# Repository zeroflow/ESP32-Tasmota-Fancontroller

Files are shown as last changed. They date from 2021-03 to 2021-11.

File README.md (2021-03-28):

# ESP32 Tasmota-Fancontroller

## THIS MODULE HAS NOT YET BEEN BUILT, WORK IN PROGRESS
 
* 4x PWM Fan Output (3 Pin Fan Control not supported)
* 1x BME280 Header
* 1x Spare Header (3V3, GND, 4x IO)

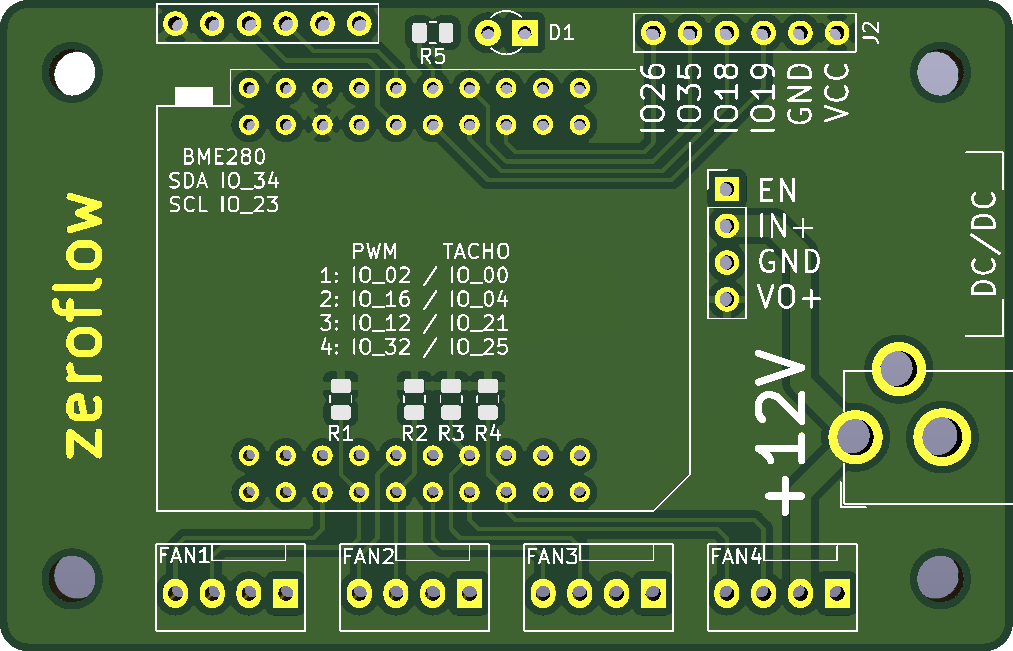
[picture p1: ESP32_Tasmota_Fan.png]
Board Screenshot


## Tasmota Config

* Individual PWM Channel control
* Gamma correction OFF (0..100 = 0%..100% PWM, by default, Tasmota uses a [Gamma Table](https://tasmota.github.io/docs/Lights/#gamma-correction))

`Backlog Setoption68 1; LedTable 0`

## Tasmota32 Template

`{"NAME":"ESP32-Fancontroller","GPIO":[352,0,416,0,353,0,0,0,418,0,0,0,417,0,1,1,0,354,0,608,0,355,1,0,0,0,0,0,419,544,640,1,0,0,0,0],"FLAG":0,"BASE":1}`

| Function | Pin |
| --- | --- |
| Sense1 | IO_00 |
| PWM1 | IO_02 |
| Sense2 | IO_04 |
| PWM3 | IO_12 |
| PWM2 | IO_16 |
| Spare | IO_18 |
| Spare | IO_19 |
| Sense3 | IO_21 |
| BME280 SCL | IO_23 |
| Sense4 | IO_25 |
| Spare | IO_26 |
| PWM4 | IO_32 |
| Link | IO_33 |
| BME280 SDA | IO_34 |
| Spare | IO_35 |

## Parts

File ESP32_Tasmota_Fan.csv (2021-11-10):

Comment | Designator | Footprint | LCSC
1uF/10V | C1 | Capacitor_SMD:C_0805_2012Metric | C1779
330uF/6.3V | C2,C4 | Capacitor_Tantalum_SMD:CP_EIA-3528-15_AVX-H | C16133
1uF | C3,C5 | Capacitor_SMD:C_0805_2012Metric | C1779
LED | D1 | LED_SMD:LED_0805_2012Metric | C2296
1N5820/SS34 | D2 | Diode_SMD:D_SMA | C8678
ZMM5V6 | D3 | Diode_SMD:D_MiniMELF | C8062
Conn_01x04 | FAN1,FAN2,FAN3,FAN4 | Connector:FanPinHeader_1x04_P2.54mm_Vertical
MountingHole | H1,H2,H3,H4 | MountingHole:MountingHole_3.2mm_M3_Pad_Via
XL1509-ADJE1 | IC1 | CSE:SOIC127P600X175-8N | C74192
Conn_01x02_Female | J1 | Connector_BarrelJack:BarrelJack_CUI_PJ-102AH_Horizontal
Conn_01x06 | J2 | Connector_PinHeader_2.54mm:PinHeader_1x06_P2.54mm_Vertical
Conn_01x10 | J3 | Connector_PinSocket_2.54mm:PinSocket_1x10_P2.54mm_Vertical
33uH | L1 | Inductor_SMD:L_TDK_SLF7045 | C13754
AO3401A | Q1 | Package_TO_SOT_SMD:SOT-23 | C15127
4k7 | R1 | Resistor_SMD:R_0805_2012Metric | C17673
100R | R3,R4,R8,R10,R12 | Resistor_SMD:R_0805_2012Metric | C17408
1k | R2 | Resistor_SMD:R_0805_2012Metric | C17513
2k7 | R20 | Resistor_SMD:R_0805_2012Metric | C17530
1k6 | R21 | Resistor_SMD:R_0805_2012Metric | C17394
10k | R5,R6,R7,R9,R11 | Resistor_SMD:R_0805_2012Metric | C17414
ESP32-WROOM-E | U1 | espressif:ESP32-WROOM-32E | C701341

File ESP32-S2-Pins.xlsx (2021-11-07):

Name | No. | Type | Fixed / Comment | Comments | GPIO | RTC GPIO | Special | ADC | DAC | Touch | JTAG | UART | SPI
GND | 1 | P | Ground
3V3 | 2 | P | Power supply | 500mA or more
IO0 | 3 | I/O/T | Bootstrap / Flashing |  | GPIO0 | RTC_GPIO0
IO1 | 4 | I/O/T |  |  | GPIO1 | RTC_GPIO1 |  | ADC1_CH0 |  | TOUCH1
IO2 | 5 | I/O/T |  |  | GPIO2 | RTC_GPIO2 |  | ADC1_CH1 |  | TOUCH2
IO3 | 6 | I/O/T |  |  | GPIO3 | RTC_GPIO3 |  | ADC1_CH2 |  | TOUCH3
IO4 | 7 | I/O/T |  |  | GPIO4 | RTC_GPIO4 |  | ADC1_CH3 |  | TOUCH4
IO5 | 8 | I/O/T |  |  | GPIO5 | RTC_GPIO5 |  | ADC1_CH4 |  | TOUCH5
IO6 | 9 | I/O/T |  |  | GPIO6 | RTC_GPIO6 |  | ADC1_CH5 |  | TOUCH6
IO7 | 10 | I/O/T |  |  | GPIO7 | RTC_GPIO7 |  | ADC1_CH6 |  | TOUCH7
IO8 | 11 | I/O/T |  |  | GPIO8 | RTC_GPIO8 |  | ADC1_CH7 |  | TOUCH8
IO9 | 12 | I/O/T |  |  | GPIO9 | RTC_GPIO9 |  | ADC1_CH8 |  | TOUCH9 |  |  | FSPIHD
IO10 | 13 | I/O/T |  |  | GPIO10 | RTC_GPIO10 |  | ADC1_CH9 |  | TOUCH10 |  |  | FSPICS0, FSPIIO4
IO11 | 14 | I/O/T |  |  | GPIO11 | RTC_GPIO11 |  | ADC2_CH0 |  | TOUCH11 |  |  | FSPID, FSPIIO5
IO12 | 15 | I/O/T |  |  | GPIO12 | RTC_GPIO12 |  | ADC2_CH1 |  | TOUCH12 |  |  | FSPICLK, FSPIIO6
IO13 | 16 | I/O/T |  |  | GPIO13 | RTC_GPIO13 |  | ADC2_CH2 |  | TOUCH13 |  |  | FSPIQ, FSPIIO7
IO14 | 17 | I/O/T |  |  | GPIO14 | RTC_GPIO14 |  | ADC2_CH3 |  | TOUCH14 |  |  | FSPIWP, FSPIDQS
IO15 | 18 | I/O/T |  |  | GPIO15 | RTC_GPIO15 | XTAL_32K_P | ADC2_CH4 |  |  |  | U0RTS
IO16 | 19 | I/O/T |  |  | GPIO16 | RTC_GPIO16 | XTAL_32K_N | ADC2_CH5 |  |  |  | U0CTS
IO17 | 20 | I/O/T |  |  | GPIO17 | RTC_GPIO17 |  | ADC2_CH6 | DAC_1 |  |  | U1TXD
IO18 | 21 | I/O/T |  |  | GPIO18 | RTC_GPIO18 |  | ADC2_CH7 | DAC_2 |  |  | U1RXD | CLK_OUT3
IO19 | 22 | I/O/T | Native USB |  | GPIO19 | RTC_GPIO19 | USB_D- | ADC2_CH8 |  |  |  | U1RTS | CLK_OUT2
IO20 | 23 | I/O/T | Native USB |  | GPIO20 | RTC_GPIO20 | USB_D+ | ADC2_CH9 |  |  |  | U1CTS | CLK_OUT1
IO21 | 24 | I/O/T |  |  | GPIO21 | RTC_GPIO21
IO26 | 25 | I/O/T | DO NOT USE | CS for PSRAM | GPIO26 |  |  |  |  |  |  |  | SPICS1
GND | 26 | P | Ground
IO33 | 27 | I/O/T |  |  | GPIO33 |  |  |  |  |  |  |  | FSPIHD, SPIIO4
IO34 | 28 | I/O/T |  |  | GPIO34 |  |  |  |  |  |  |  | FSPICS0, SPIIO5
IO35 | 29 | I/O/T |  |  | GPIO35 |  |  |  |  |  |  |  | FSPID, SPIIO6
IO36 | 30 | I/O/T |  |  | GPIO36 |  |  |  |  |  |  |  | FSPICLK, SPIIO7
IO37 | 31 | I/O/T |  |  | GPIO37 |  |  |  |  |  |  |  | FSPIQ, SPIDQS
IO38 | 32 | I/O/T |  |  |  |  |  |  |  |  |  |  | FSPIWP
IO39 | 33 | I/O/T |  |  | GPIO39 |  |  |  |  |  | MTCK |  | CLK_OUT3
IO40 | 34 | I/O/T |  |  | GPIO40 |  |  |  |  |  | MTDO |  | CLK_OUT2
IO41 | 35 | I/O/T |  |  | GPIO41 |  |  |  |  |  | MTDI |  | CLK_OUT1
IO42 | 36 | I/O/T |  |  | GPIO42 |  |  |  |  |  | MTMS
TXD0 | 37 | I/O/T | Flashing |  | GPIO43 |  |  |  |  |  |  | U0TXD | CLK_OUT1
RXD0 | 38 | I/O/T | Flashing |  | GPIO44 |  |  |  |  |  |  | U0RXD | CLK_OUT2
IO45 | 39 | I/O/T | Bootstrap |  | GPIO45
IO46 | 40 | I | Bootstrap |  | GPIO46
EN | 41 | I | Pull-Up | R = 10 kΩ and C = 1 µF | High: on, enables the chip. Low: off, the chip powers off. Note: Do not leave the EN pin floating.
GND | 42 | P | Ground
https://docs.espressif.com/projects/esp-idf/en/latest/esp32s2/api-reference/peripherals/gpio.html
Strapping pin: GPIO0, GPIO45 and GPIO46 are strapping pins. For more infomation, please refer to ESP32-S2 datasheet (https://www.espressif.com/sites/default/files/documentation/esp32-s2_datasheet_en.pdf)
SPI0/1: GPIO26-32 are usually used for SPI flash and PSRAM and not recommended for other uses.
JTAG: GPIO39-42 are usually used for inline debug.
GPI: GPIO46 is fixed to pull-down and is input only.

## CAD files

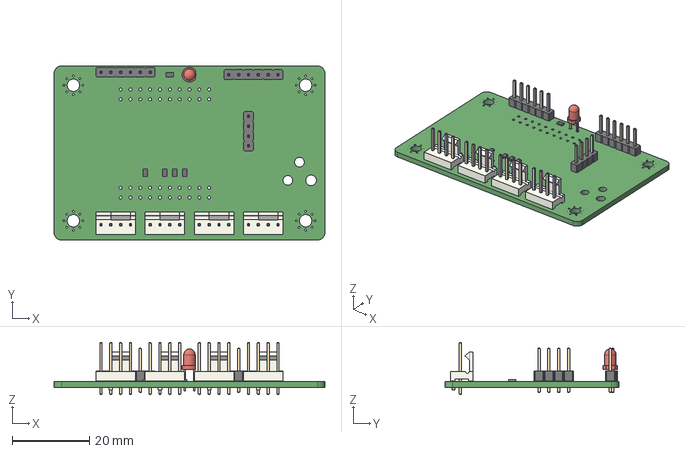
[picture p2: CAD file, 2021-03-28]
ESP32_Tasmota_Fan.step
70.0 x 45.0 x 13.5 mm

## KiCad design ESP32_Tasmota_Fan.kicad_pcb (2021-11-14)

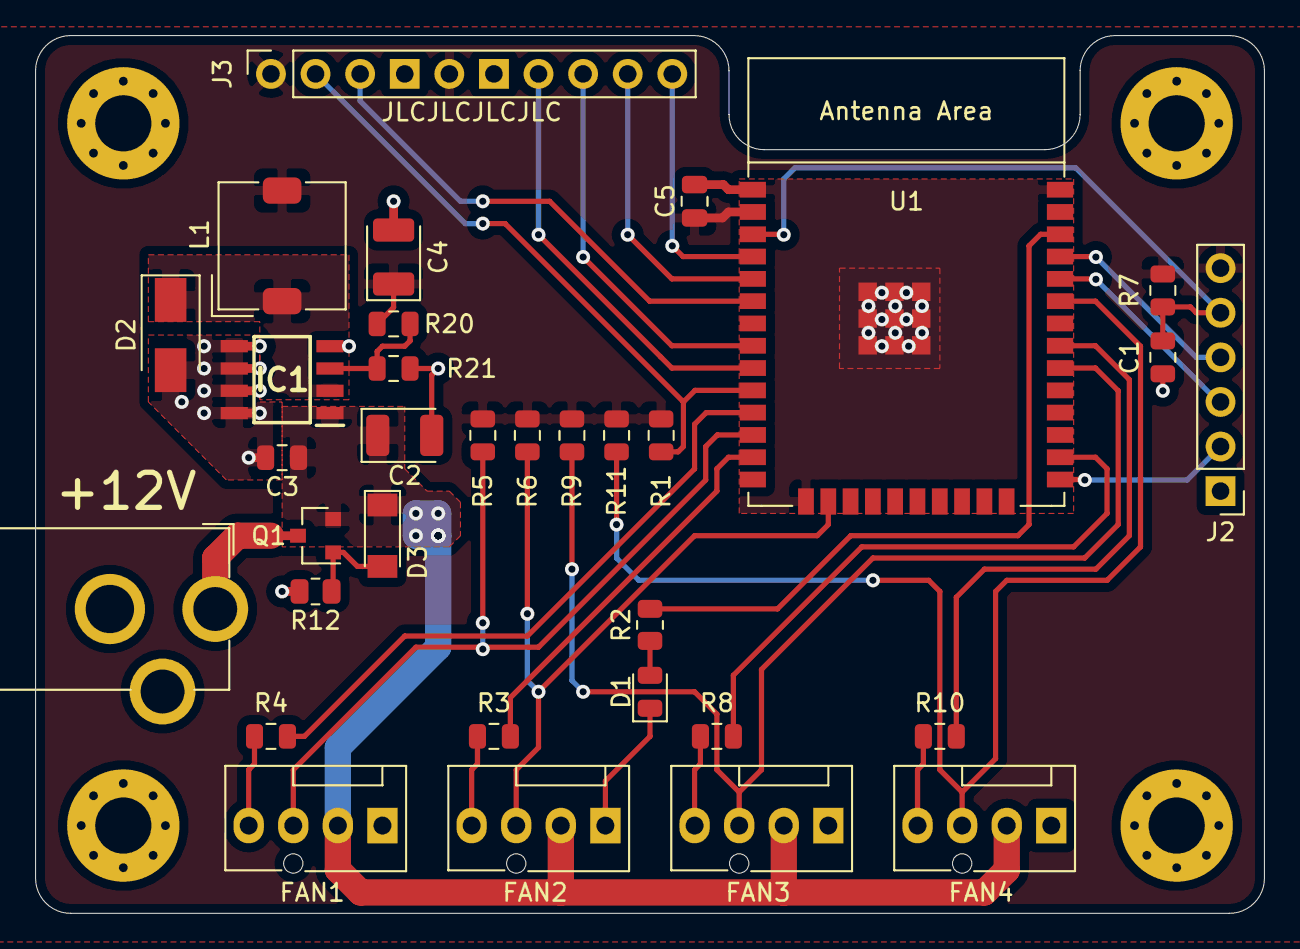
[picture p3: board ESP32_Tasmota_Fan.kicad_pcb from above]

Board: 2 copper layers, 70.0 x 50.0 mm, 37 parts (0 on the bottom side), 31 nets.

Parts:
C1: 1uF/10V; C_0805_2012Metric
C2, C4: 330uF/6.3V; CP_EIA-3528-15_AVX-H
C3, C5: 1uF; C_0805_2012Metric
D1: LED; LED_0805_2012Metric
D2: 1N5820/SS34; D_SMA
D3: ZMM5V6; D_MiniMELF
FAN1, FAN2, FAN3, FAN4: Conn_01x04; FanPinHeader_1x04_P2.54mm_Vertical
H1, H2, H3, H4: MountingHole; MountingHole_3.2mm_M3_Pad_Via
IC1: XL1509-ADJE1; SOIC127P600X175-8N
J1: Conn_01x02_Female; BarrelJack_CUI_PJ-102AH_Horizontal
J2: Conn_01x06; PinHeader_1x06_P2.54mm_Vertical
J3: Conn_01x10; PinSocket_1x10_P2.54mm_Vertical
L1: 33uH; L_TDK_SLF7045
Q1: AO3401A; SOT-23
R1: 4k7; R_0805_2012Metric
R2: 1k; R_0805_2012Metric
R3, R4, R8, R10, R12: 100R; R_0805_2012Metric
R5, R6, R7, R9, R11: 10k; R_0805_2012Metric
R20: 2k7; R_0805_2012Metric
R21: 1k6; R_0805_2012Metric
U1: ESP32-WROOM-E; ESP32-WROOM-32E

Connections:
+3V3: C4.1, C5.1, J2.6, J3.1, J3.5, L1.2, R1.1, R5.1, R6.1, R7.1, R9.1, R11.1, R20.1, U1.2
+12V: C2.1, C3.1, D3.1, FAN1.2, FAN2.2, FAN3.2, FAN4.2, IC1.1, Q1.2
/DC/DC Buck/FB: IC1.3, R20.2, R21.1
/DC/DC Buck/OUTPUT: D2.1, IC1.2, L1.1
/ESP32 Core/EN: C1.1, J2.5, R7.2, U1.3
/ESP32 Core/IO0: J2.2, U1.25
/ESP32 Core/RX: J2.3, U1.34
/ESP32 Core/TX: J2.4, U1.35
/EXT1: J3.3, U1.6
/EXT2: J3.9, U1.5
/EXT3: J3.10, U1.4
/FAN 1/PWM_Ctrl: FAN1.4, R4.2
/LINK: R2.1, U1.36
/OneWire: J3.2, R1.2, U1.10
/PWM1: R4.1, U1.11
/PWM2: R3.1, U1.13
/PWM3: R8.1, U1.26
/PWM4: R10.1, U1.31
/SCL: J3.7, U1.9
/SDA: J3.8, U1.8
/SENSE1: FAN1.3, R5.2, U1.12
/SENSE2: FAN2.3, R6.2, U1.16
/SENSE3: FAN3.3, R9.2, U1.30
/SENSE4: FAN4.3, R11.2, U1.33
/VIN: J1.1, Q1.3
/sheet61958B6B/PWM_Ctrl: FAN4.4, R10.2
/sheet619566BF/PWM_Ctrl: FAN2.4, R3.2
/sheet61957927/PWM_Ctrl: FAN3.4, R8.2
GND: C1.2, C2.2, C3.2, C4.2, C5.2, D1.1, D2.2, FAN1.1, FAN2.1, FAN3.1, FAN4.1, IC1.4, IC1.5, IC1.6, IC1.7, IC1.8, J1.2, J2.1, J3.4, J3.6, R12.2, R21.2, U1.1, U1.15, U1.38, U1.39
unnamed: D1.2, R2.2
unnamed: D3.2, Q1.1, R12.1

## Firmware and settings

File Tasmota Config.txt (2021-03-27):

Setoption68 1

Template
========

{"NAME":"ESP32-Fans","GPIO":[416,0,352,0,353,0,0,0,418,0,0,0,417,0,1,0,0,354,0,0,0,355,1,0,0,0,0,0,419,640,608,0,0,0,0,0],"FLAG":0,"BASE":1}

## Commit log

2021-03-27 Initial Drop
    First version, still waiting for verification of DC input jack availability
    [ESP32_Tasmota_Fan-B_Cu.gbr, ESP32_Tasmota_Fan-B_Mask.gbr, ESP32_Tasmota_Fan-B_Paste.gbr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]
2021-03-28 Production Version
    [ESP32_Tasmota_Fan-B_Cu.gbr, ESP32_Tasmota_Fan-B_Mask.gbr, ESP32_Tasmota_Fan-B_Paste.gbr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]
2021-04-29 Move I2C Pins for BME280
    IO34 can only do input, so it is not suitable for I2C
    [ESP32_Tasmota_Fan-B_Cu.gbr, ESP32_Tasmota_Fan-B_Mask.gbr, ESP32_Tasmota_Fan-B_Paste.gbr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]
2021-11-07 First step for new design
    split up design into multiples
    added voltage regulator available at JLCPCB
    [BuckConverter.sch, ESP32-S2-Pins.xlsx, ESP32-S2-WROOM.kicad_pcb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]
2021-11-07 First layouting
    [BuckConverter.sch, ESP32-S2.sch, ESP32_Tasmota_Fan.kicad_pcb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]
2021-11-10 First iteration with new ES32 - but not S2
    [BuckConverter.sch, ESP32-S2.sch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]
2021-11-10 Include fabrication outputs
    [ESP32_Tasmota_Fan-B_Cu.gbr, ESP32_Tasmota_Fan-B_Mask.gbr, ESP32_Tasmota_Fan-B_Paste.gbr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]
2021-11-10 Add JLC template
    [ESP32_Tasmota_Fan.kicad_pcb]
2021-11-14 Version open for review
    [ESP32-S2.sch, ESP32_Tasmota_Fan.kicad_pcb, ESP32_Tasmota_Fan.sch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]
